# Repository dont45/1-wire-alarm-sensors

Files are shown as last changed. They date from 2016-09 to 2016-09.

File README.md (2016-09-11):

# 1-wire-alarm-sensors
Collection of 1-wire sensor devices

A switch 'closure' sensor such as a typical magnetic reed switch is connected to the photonAlarm 
by use of a 1-wire device such as a ds2406 or ds2413.  These devices provide two gpio 'pins' controlled
by 1-wire commands from the photonAlarm.  The gpio pins are generally labled PIO pins, PIO-A and PIO-B
for the two devices mentioned.  These are bi-directional open drain pins which can serve to detect a 
switch closure or drive a device for output.  The advantage of this design is that a single wire (and a ground)
connects all the alarm sensors, with the 1-wire devices being connected in a varity of topologies, i.e. star,
multi-drop, or straight line.

Since in the simplest configuration there is no voltage supplied to the sensor, just the 1-wire data line,
there is no voltage to detect by the sensor switch closing.  In order to keep the sensor network in the
spirit of 1-wire, a method, called parasitic power, can be used to power the detection circuit of the
reed switch.  This method is implemented by a parasitic charge circuit which taps the 1-wire data line
to keep a capacitor charged.  The charge on this capacitor is used to drive the voltage detection at the
device's PIO port.  This design is attached as sensor-2406p+.  Included are Eagle files as well as the .pdf's.

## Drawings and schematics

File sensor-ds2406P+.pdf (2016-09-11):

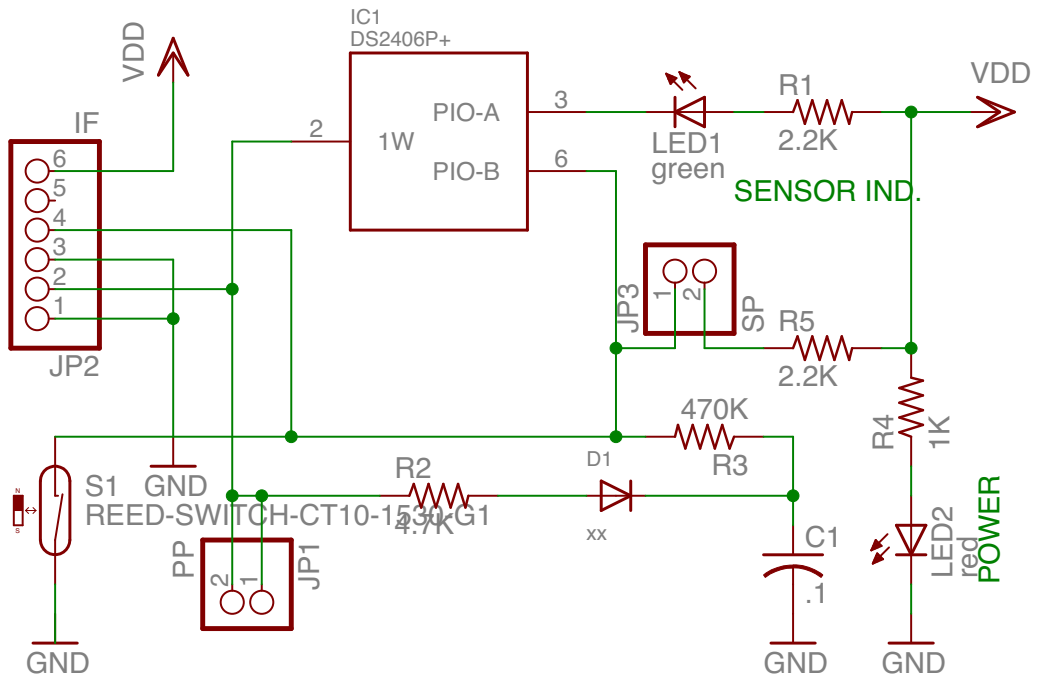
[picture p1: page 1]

Document Number: | REV:

Date: 9/11/16 12:30 PM | Sheet: 1/1

9/11/16 1:57 PM /Users/dont/Documents/eagle/sensor-board-2406P+/sensor-ds2406P+.sch (Sheet: 1/1)

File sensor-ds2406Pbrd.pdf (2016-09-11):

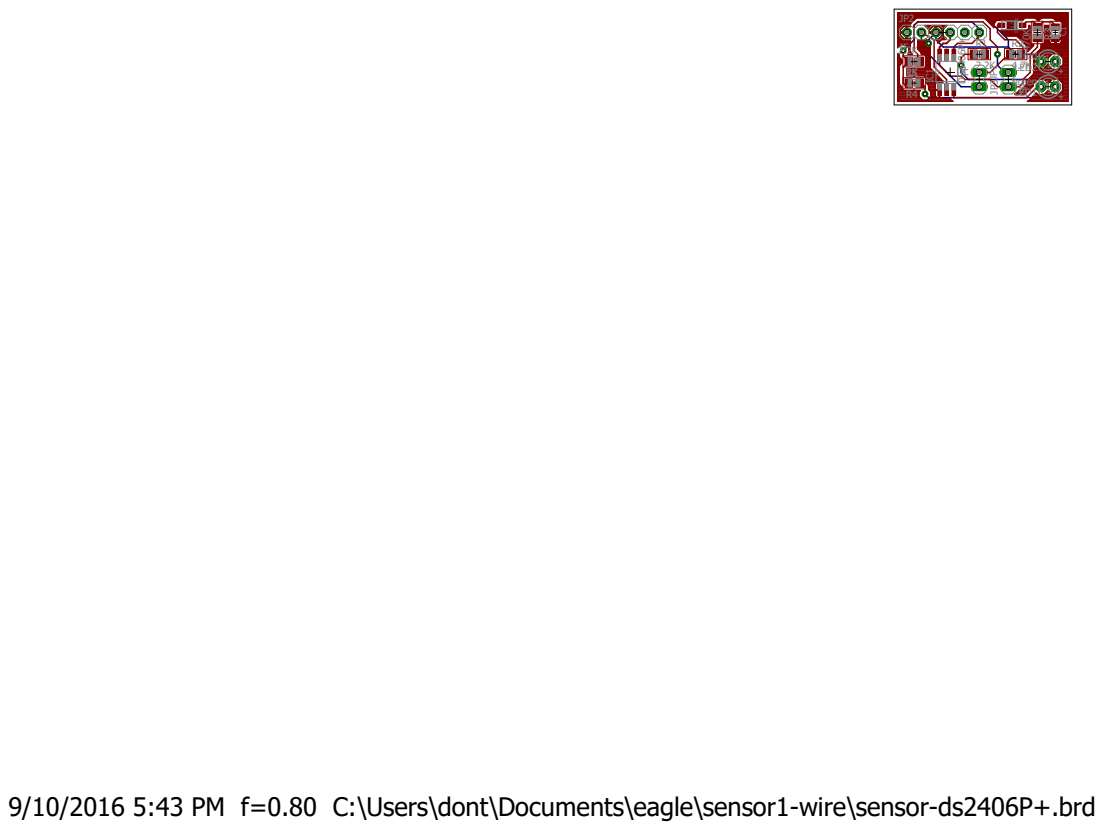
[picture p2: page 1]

9/10/2016 5:43 PM f=0.80 C:\Users\dont\Documents\eagle\sensor1-wire\sensor-ds2406P+.brd C1

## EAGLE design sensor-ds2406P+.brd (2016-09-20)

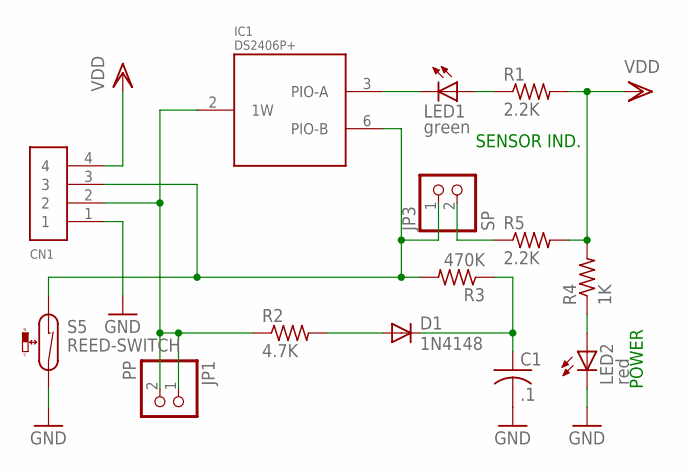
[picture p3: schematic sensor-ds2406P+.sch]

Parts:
C1: .1; C0805K
CN1: 1X4-BIG; 1X04-BIG
D1: 1N4148; SOT23
IC1: DS2406P+; SO06
JP1: PP; 1X02
JP3: SP; 1X02
LED1: green; LED3MM
LED2: red; LED3MM
R1, R5: 2.2K; R0805
R2: 4.7K; R0805
R3: 470K; R0805
R4: 1K; R0805
S5: REED-SWITCH; MK15

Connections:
GND: C1.2, CN1.1, IC1.1 (GND), LED2.K (C), S5.2
IO: CN1.2, IC1.2 (1W), JP1.1, JP1.2, R2.1
unnamed: LED1.A, R1.1
unnamed: D1.1 (A), R2.2
unnamed: C1.1, D1.3 (C), R3.1
unnamed: LED2.A, R4.1
unnamed: JP3.2, R5.1
PIO$A: IC1.3 (PIO-A), LED1.K (C)
PIO$B: CN1.3, IC1.6 (PIO-B), JP3.1, R3.2, S5.1
VDD: CN1.4, IC1.4 (VDD), R1.2, R4.2, R5.2

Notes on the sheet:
SENSOR IND.
POWER

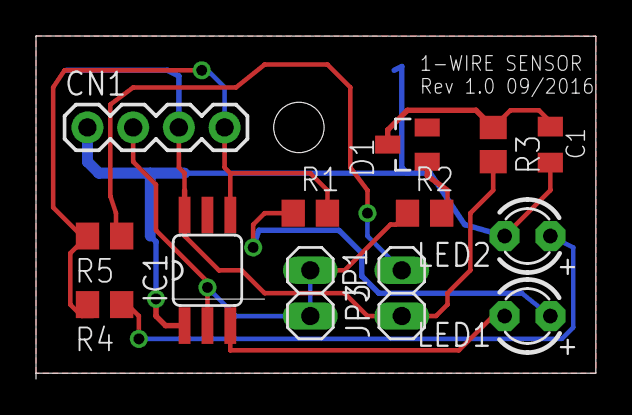
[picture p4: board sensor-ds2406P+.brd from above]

Board: 2 copper layers, 31.1 x 19.1 mm, 14 parts (1 on the bottom side), 10 nets.
